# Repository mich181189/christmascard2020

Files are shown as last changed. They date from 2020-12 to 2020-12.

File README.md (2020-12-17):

# christmascard2020
I made a christmas card with WS2812B LEDs and it supports Micropython!

There is some HTML documentation generated from the /docs/ folder at https://mich181189.github.io/christmascard2020/index.html

The board is intended to run Micropython, a fork of which (with some additions to support this hardware) is available here: https://github.com/mich181189/christmascard2020_micropython

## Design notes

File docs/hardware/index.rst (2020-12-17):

Christmas Card Hardware / Design Notes
======================================

.. toctree::
   :maxdepth: 2

   advanced
   ../flash_sh

.. rubric:: The hardware consists of:

* STM32F401RET6 Microcontroller
* 28 WS2812B LEDs (`Datasheet <../_static/WS2812B.pdf>`_)
* LM75B i2c Temperature Sensor
* A USB Connector

The microcontroller was chosen as the cheapest one available on `JLCPCB's SMT assembly service <https://jlcpcb.com/smt-assembly>`_ with decent Micropython support. This entire project was desgned in a bit of a rush 😅 

The USB connector is a full-sized B connector. This is because it was relatively easy to solder on once I received the PCBs from JLC - I didn't fancy separately reflowing a connector on - if I had more time, I'd have chosen micro-B or maybe even USB-C

The name label was done with a Brother P-Touch label maker. I had originally intended to Sharpie on names, but it started to smudge a bit. I realised I had some 6mm tape for my label maker that worked nicely.

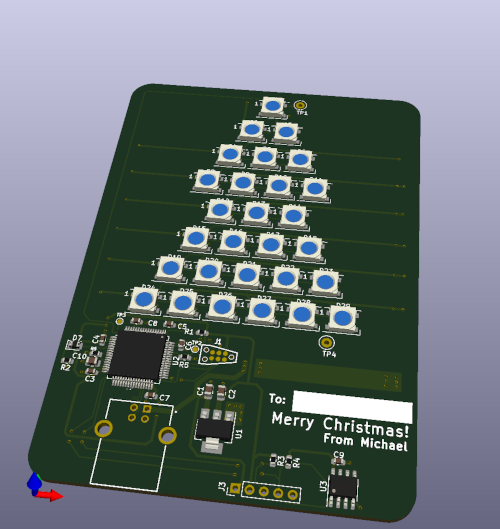
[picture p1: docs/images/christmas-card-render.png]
Render of PCB


.. rubric:: Some Links

* The Schematic `is available as a PDF <../_static/schematic_1_0.pdf>`_ 
* The hardware design is `available on GitHub <https://github.com/mich181189/christmascard2020>`_
    * If you want to play with  the hardware design, it was designed in `KiCad <https://kicad.org/>`_
* The board runs `Micropython <http://micropython.org/>`_
* In case you need the firmware for some reason:
    * `firmware0.bin <../_static/firmware0.bin>`_ (0x08000000)
    * `firmware1.bin <../_static/firmware1.bin>`_ (0x08020000)
    * `init_fs.bin <../_static/init_fs.bin>`_ (0x8004000)
    * :doc:`../flash_sh`

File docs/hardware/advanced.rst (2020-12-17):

More Advanced Ideas
====================
This page contains some hints/tips/suggestions for things you might want to try if you get bored of the board as is.

Connecting More LEDs
---------------------
There are two test points on the board, TP1 and TP4 that are in the LED chain. *TP1* is the output of *PB0* on the microcontroller. This is probbaly of limited use for extension since while you could tap into it, the LEDs would be in parallel with those on the board, which doesn't sound incredibly useful. *TP4* however, may be more useful. It is the *DOUT* pin of the last LED in the chain. This could be connected to a string of WS2812 LEDs. Then, when you init the module, you could specify the extra count

>>> ws2812.init(28+60)

I really have no idea how many LEDs could be added this way, however the code for driving them uses quite a memory-efficient way of sending the data, so I suspect the number is actually quite high. Memory usage is 3 bytes per LED, plus 48 bytes of scratch space for the actual sending functions.

Connecting I2C Peripherals
--------------------------
There is a pin header on the bottom edge of the board. As well as power and data, this connects to the I2C bus (shared with the LM75 temperature sensor)

+-----------------+
| Pin  | Function |
+======+==========+
| 1    | +5V      |
+------+----------+
| 2    | +3.3V    |
+------+----------+
| 3    | SCL      |
+------+----------+
| 4    | SDA      |
+------+----------+
| 5    | GND      |
+------+----------+

.. warning::
	The SCL and SDA data lines run at 3.3V. 5V devices can be connected, as long as they do not try to pull these lines to the +5V rail - Since I2C devices should only be pulling the line low, this should not be a problem, except that some (many?) breakout boards contain their own pullup resistors to their power rail.

These devices can then be addressed much like any other device. For example, if you were trying to communicate with the LM75B sensor on the board using raw I2C commands:

>>> import machine
>>> i2c = machine.I2C(1, freq=400000) # 400KHz I2C bus on channel 1 (the one broken out on the connector)
>>> result = i2c.readfrom_mem(72, 0x00, 2) # read 2 bytes from register 0 on device with address 72 aka 0x48
>>> result
b'\x17\xa0'

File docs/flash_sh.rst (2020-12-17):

My Board Flashing Script
==========================

This is the script I used to flash the board. It was run from ports/stm32 in the Micropython source tree `(GitHub Link) <https://github.com/mich181189/christmascard2020_micropython>`_

It makes use of an initial filesystem I created by copying the files to a board, then dumping the relevant section of flash. I then used the *fatlabel* utility to relabel it as CCARD2020

I used an STLink V2 for the flashing.

.. literalinclude:: examples/flash.sh

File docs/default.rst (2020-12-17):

The Default main.py Script
==========================

This is the `main.py` file that was on the board when you received it, in case you need it

.. literalinclude:: examples/default_main.py

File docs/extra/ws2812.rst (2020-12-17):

WS2812 Module
==============
.. py:module::ws2812

.. py:function:: init(count)
	Sets up the WS2812 module to handle *count* LEDs

.. py:function:: set_led(led, red, green, blue)

	Sets the colour of the led, identified by index *led* to the colour specified by *red*, *green* and *blue* which are integers from 0 to 255.

	.. note::
 		These LEDs are very bright! Values between 0 and 25 are probably easily bright enough! Setting too many LEDs to a high value can cause fairly high current draw, and the PCB can get very hot.

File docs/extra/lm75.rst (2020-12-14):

lm75 Module
===========
.. py:module::lm75

Handler for LM75 i2c temperature sensor. The LM75 temperature sensor is connected to the I2C bus, and continuously measures temperature, unless it is explicitly shutdown (see :py:meth:`lm75.LM75.shutdown`)

.. py:module:: lm75
.. py:class:: LM75(i2c [, address=72])

	Constructs an LM75 object. Takes an I2C object and optionally, an address of the LM75

	.. py:method:: get_temperature()

	Gets the current temperature, as measured by the LM75 module, in `degrees celsius <https://en.wikipedia.org/wiki/Celsius>`_

	Reading while the device is shutdown will result in the last temperature reading captured before the sensor was shutdown.

	.. py:method:: shutdown()

	Shuts down the LM75 temperature sensor, reducing current consumption. Also might be useful to prevent the temperature sensor from heating itself up too much, affecting measurements.

	To reverse this, call :py:meth:`wakeup`

	.. py:method:: wakeup()

	Wakes up the LM75, after a call to :py:meth:`shutdown`

	.. py:method:: is_shutdown()

	Returns True if the LM75 sensor is in a shutdown state

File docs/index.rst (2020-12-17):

.. Christmas Card 2020 documentation master file, created by
   sphinx-quickstart on Mon Dec 14 18:30:20 2020.
   You can adapt this file completely to your liking, but it should at least
   contain the root `toctree` directive.

Welcome to the Christmas Card 2020 docs!
===============================================

If you are reading this, you have probably received a christmas card from me. Or, maybe, you stumbled upon this project and are curious about  what I created.
This card is, in fact, a `Micropython <http://micropython.org/>`_ development board! It can, of course, be 
used as a simple decoration, but it is also programmable to your liking!

Table Of Contents
======================

.. toctree::
   :maxdepth: 2

   getting_started
   Hardware / Design Notes <hardware/index>
   extra/index
   default

Indices and tables
==================

* :ref:`genindex`
* :ref:`modindex`
* :ref:`search`

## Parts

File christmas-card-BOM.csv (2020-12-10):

Comment | Designator | Footprint | LCSC
4.7uF | C1,C2,C10 | Capacitor_SMD:C_0805_2012Metric | C1779
100nF | C3,C4,C5,C6,C7,C8,C9 | Capacitor_SMD:C_0603_1608Metric | C14663
WS2812B | D1,D2,D3,D4,D5,D6,D8,D9,D10,D11,D12,D13,D14,D15,D16,D17,D18,D19,D20,D21,D22,D23,D24,D25,D26,D27,D28,D29 | LED_SMD:LED_WS2812B_PLCC4_5.0x5.0mm_P3.2mm | C114586
LED_ALT | D7 | Diode_SMD:D_0805_2012Metric | C84256
10K | R1,R3,R4,R5,R6 | Resistor_SMD:R_0603_1608Metric | C25804
270R | R2 | Resistor_SMD:R_0603_1608Metric | C22966
AMS1117-3.3 | U1 | Package_TO_SOT_SMD:SOT-223-3_TabPin2 | C6186
STM32F401RETx | U2 | Package_QFP:LQFP-64_10x10mm_P0.5mm | C116978
LM75B | U3 | Package_SO:SOIC-8_3.9x4.9mm_P1.27mm | C34565

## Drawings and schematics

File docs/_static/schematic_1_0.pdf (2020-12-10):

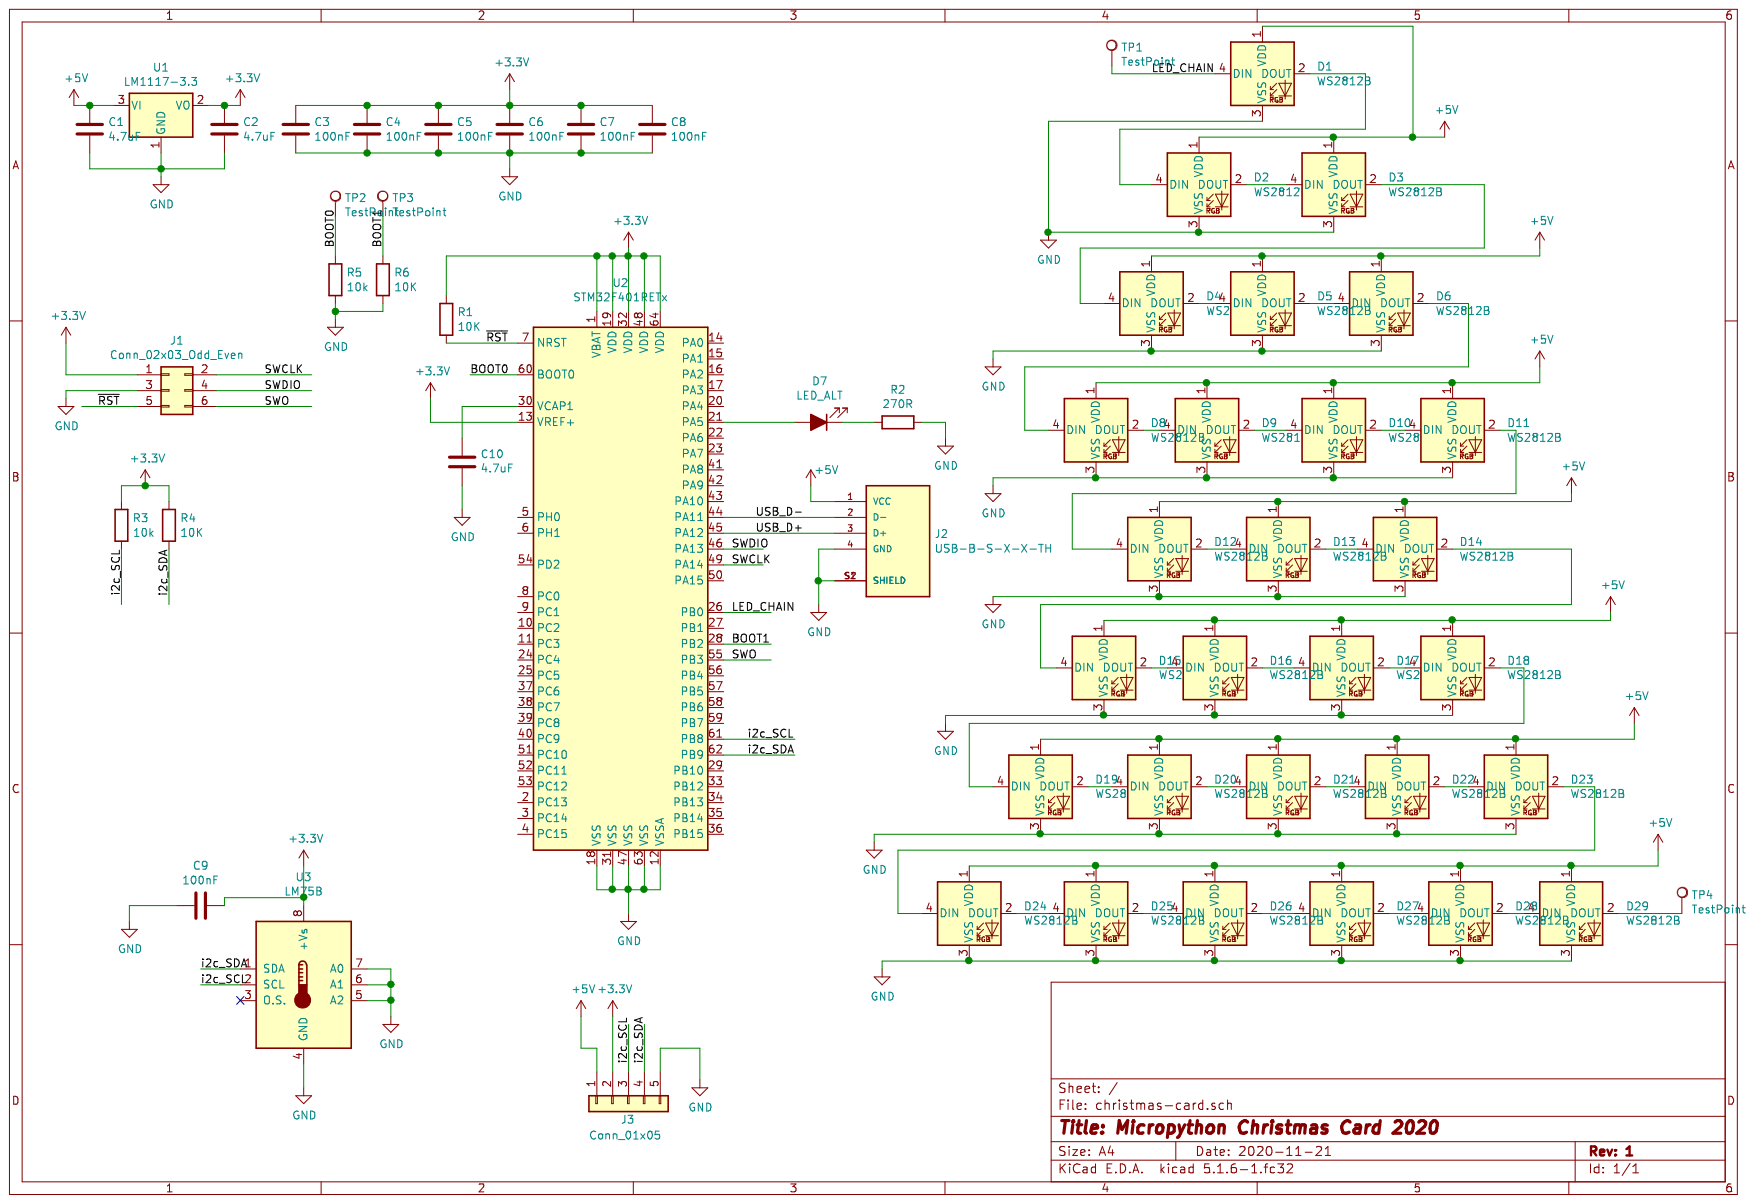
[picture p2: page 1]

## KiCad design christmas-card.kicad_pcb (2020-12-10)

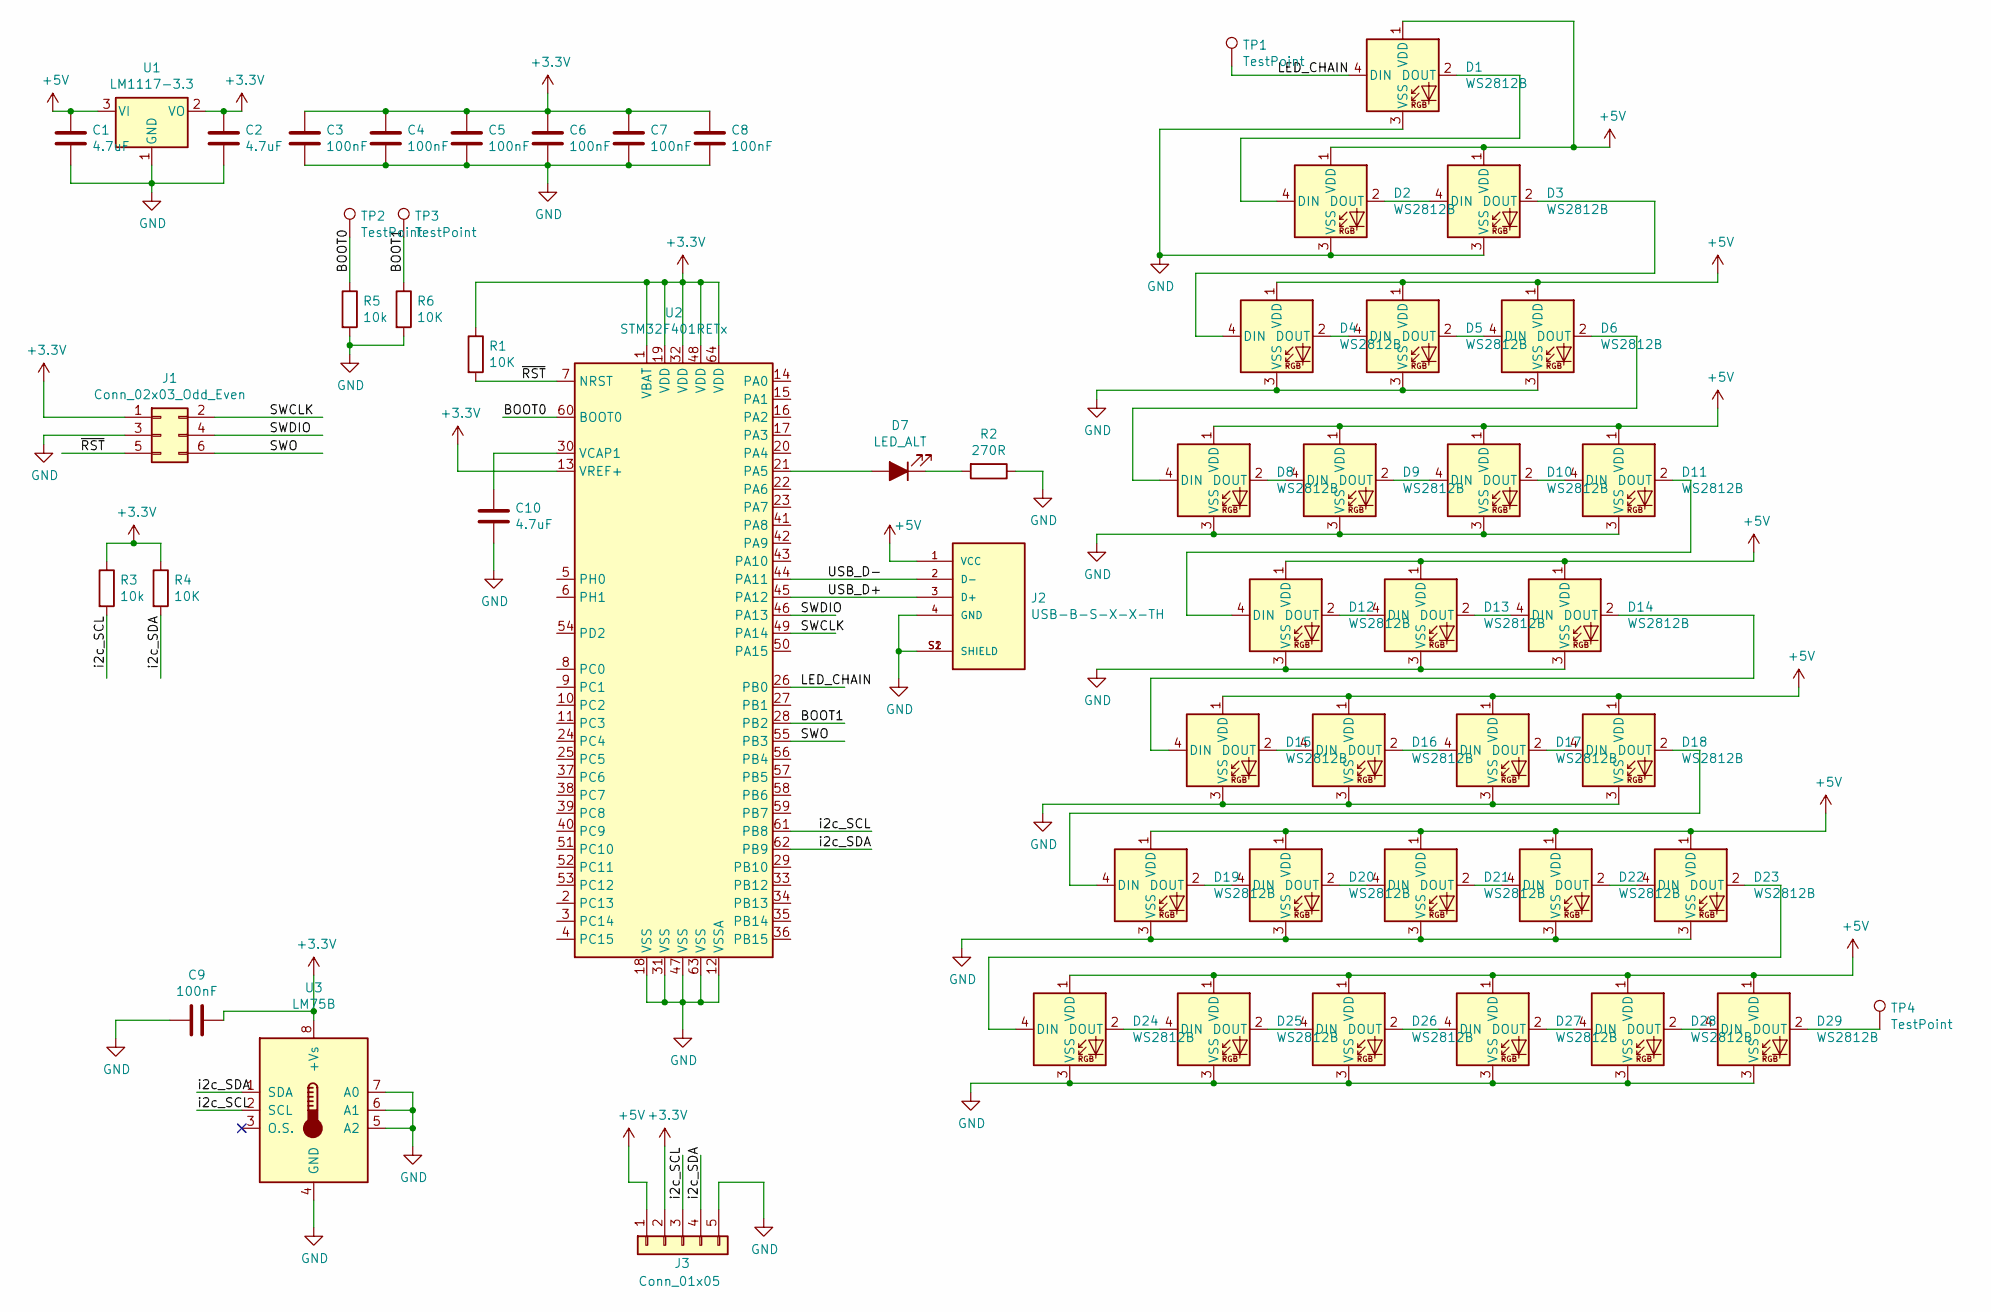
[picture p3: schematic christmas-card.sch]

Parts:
C1, C2, C10: 4.7uF; C_0805_2012Metric
C3, C4, C5, C6, C7, C8, C9: 100nF; C_0603_1608Metric
D1, D2, D3, D4, D5, D6, D8, D9, D10, D11, D12, D13, D14, D15, D16, D17, D18, D19, D20, D21, D22, D23, D24, D25, D26, D27, D28, D29: WS2812B; LED_WS2812B_PLCC4_5.0x5.0mm_P3.2mm
D7: LED_ALT; D_0805_2012Metric
J1: Conn_02x03_Odd_Even; TC2030-MCP-NL
J2: USB-B-S-X-X-TH; SAMTEC_USB-B-S-X-X-TH; PARTREV Q
J3: Conn_01x05; PinHeader_1x05_P2.54mm_Vertical
R1, R4, R6: 10K; R_0603_1608Metric
R2: 270R; R_0603_1608Metric
R3, R5: 10k; R_0603_1608Metric
TP1, TP4: TestPoint; TestPoint_Loop_D1.80mm_Drill1.0mm_Beaded
TP2, TP3: TestPoint; TestPoint_Pad_D1.0mm
U1: LM1117-3.3; SOT-223-3_TabPin2
U2: STM32F401RETx; LQFP-64_10x10mm_P0.5mm
U3: LM75B; SOIC-8_3.9x4.9mm_P1.27mm

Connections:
+3V3: C2.1, C3.1, C4.1, C5.1, C6.1, C7.1, C8.1, C9.1, J1.1, J3.2, R1.1, R3.1, R4.1, U1.2 (VO), U2.1 (VBAT), U2.13 (VREF+), U2.19 (VDD), U2.32 (VDD), U2.48 (VDD), U2.64 (VDD), U3.8 (+Vs)
+5V: C1.1, D1.1 (VDD), D2.1 (VDD), D3.1 (VDD), D4.1 (VDD), D5.1 (VDD), D6.1 (VDD), D8.1 (VDD), D9.1 (VDD), D10.1 (VDD), D11.1 (VDD), D12.1 (VDD), D13.1 (VDD), D14.1 (VDD), D15.1 (VDD), D16.1 (VDD), D17.1 (VDD), D18.1 (VDD), D19.1 (VDD), D20.1 (VDD), D21.1 (VDD), D22.1 (VDD), D23.1 (VDD), D24.1 (VDD), D25.1 (VDD), D26.1 (VDD), D27.1 (VDD), D28.1 (VDD), D29.1 (VDD), J2.1 (VCC), J3.1, U1.3 (VI)
/BOOT0: R5.1, TP2.1, U2.60 (BOOT0)
/BOOT1: R6.1, TP3.1, U2.28 (PB2)
/LED_CHAIN: D1.4 (DIN), TP1.1, U2.26 (PB0)
/SWCLK: J1.2, U2.49 (PA14)
/SWDIO: J1.4, U2.46 (PA13)
/SWO: J1.6, U2.55 (PB3)
/USB_D+: J2.3 (D+), U2.45 (PA12)
/USB_D-: J2.2 (D-), U2.44 (PA11)
/i2c_SCL: J3.3, R3.2, U2.61 (PB8), U3.2 (SCL)
/i2c_SDA: J3.4, R4.2, U2.62 (PB9), U3.1 (SDA)
/~RST: J1.5, R1.2, U2.7 (NRST)
GND: C1.2, C2.2, C3.2, C4.2, C5.2, C6.2, C7.2, C8.2, C9.2, C10.1, D1.3 (VSS), D2.3 (VSS), D3.3 (VSS), D4.3 (VSS), D5.3 (VSS), D6.3 (VSS), D8.3 (VSS), D9.3 (VSS), D10.3 (VSS), D11.3 (VSS), D12.3 (VSS), D13.3 (VSS), D14.3 (VSS), D15.3 (VSS), D16.3 (VSS), D17.3 (VSS), D18.3 (VSS), D19.3 (VSS), D20.3 (VSS), D21.3 (VSS), D22.3 (VSS), D23.3 (VSS), D24.3 (VSS), D25.3 (VSS), D26.3 (VSS), D27.3 (VSS), D28.3 (VSS), D29.3 (VSS), J1.3, J2.4 (GND), J2.S1 (SHIELD), J2.S2 (SHIELD), J3.5, R2.1, R5.2, R6.2, U1.1 (GND), U2.12 (VSSA), U2.18 (VSS), U2.31 (VSS), U2.47 (VSS), U2.63 (VSS), U3.4 (GND), U3.5 (A2), U3.6 (A1), U3.7 (A0)
unnamed: C10.2, U2.30 (VCAP1)
unnamed: D1.2 (DOUT), D2.4 (DIN)
unnamed: D2.2 (DOUT), D3.4 (DIN)
unnamed: D3.2 (DOUT), D4.4 (DIN)
unnamed: D4.2 (DOUT), D5.4 (DIN)
unnamed: D5.2 (DOUT), D6.4 (DIN)
unnamed: D6.2 (DOUT), D8.4 (DIN)
unnamed: D7.1 (K), R2.2
unnamed: D7.2 (A), U2.21 (PA5)
unnamed: D8.2 (DOUT), D9.4 (DIN)
unnamed: D10.2 (DOUT), D11.4 (DIN)
unnamed: D9.2 (DOUT), D10.4 (DIN)
unnamed: D11.2 (DOUT), D12.4 (DIN)
unnamed: D12.2 (DOUT), D13.4 (DIN)
unnamed: D13.2 (DOUT), D14.4 (DIN)
unnamed: D14.2 (DOUT), D15.4 (DIN)
unnamed: D15.2 (DOUT), D16.4 (DIN)
unnamed: D16.2 (DOUT), D17.4 (DIN)
unnamed: D17.2 (DOUT), D18.4 (DIN)
unnamed: D18.2 (DOUT), D19.4 (DIN)
unnamed: D19.2 (DOUT), D20.4 (DIN)
unnamed: D20.2 (DOUT), D21.4 (DIN)
unnamed: D21.2 (DOUT), D22.4 (DIN)
unnamed: D22.2 (DOUT), D23.4 (DIN)
unnamed: D23.2 (DOUT), D24.4 (DIN)
unnamed: D24.2 (DOUT), D25.4 (DIN)
unnamed: D25.2 (DOUT), D26.4 (DIN)
unnamed: D26.2 (DOUT), D27.4 (DIN)
unnamed: D27.2 (DOUT), D28.4 (DIN)
unnamed: D28.2 (DOUT), D29.4 (DIN)
unnamed: D29.2 (DOUT), TP4.1

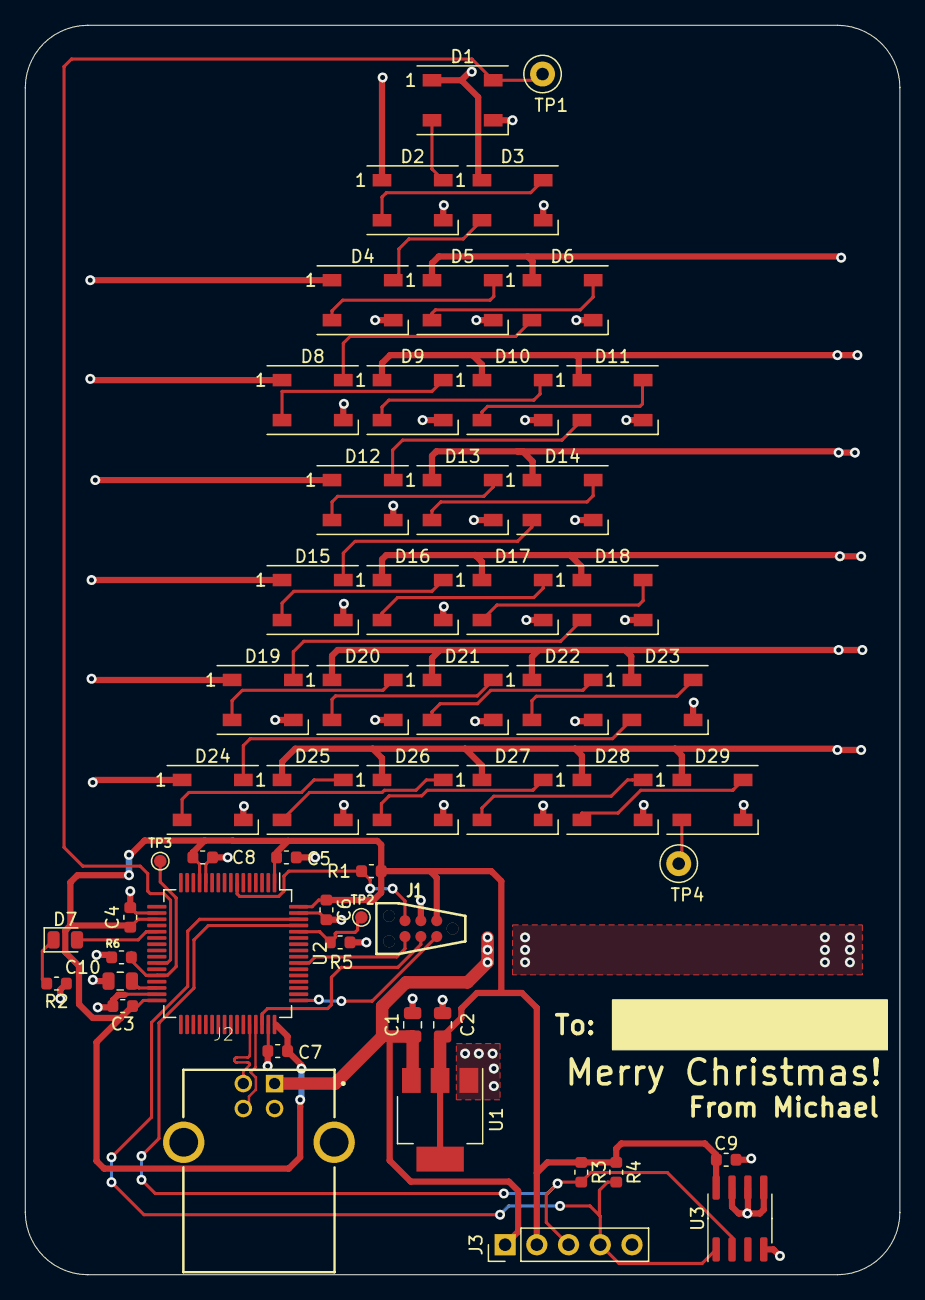
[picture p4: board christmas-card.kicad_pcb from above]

Board: 2 copper layers, 70.0 x 100.0 mm, 55 parts (0 on the bottom side), 45 nets.

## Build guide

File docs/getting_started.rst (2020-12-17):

Getting Started
===============

.. contents::
    :depth: 3

An introduction to the Hardware
-------------------------------

The christmas card is a `Micropython <http://micropython.org/>`_ board, with 28 WS2812 LEDs (sometimes called NeoPixels). It has a USB connector, providing it with 5V power. As supplied, it pulls about 20mA so it can run from a decent power bank for quite a while. This depends very much on the script that's running though.

It can be simply used as a christmas decoration, though it can also be a lot more fun than that!

When plugged into a computer, it appears as both a mass storage device, and a serial port. Together, these allow the pattern to be customised.

There is also a temperature sensor on the board. Because why not?!

For more details of the hardware specs, see :doc:`hardware/index`

Connecting to the Board
-----------------------

Plug one end of a USB cable into the board. Plug the other end into your computer. Yep, thats all there is to it. Now read the next sections for details of what you can do with this!

Storage
^^^^^^^^

When connected to a computer, it will show up as a storage device. On this storage device you will find a few files:

* **boot.py** - this is run at startup, to configure the hardware. It doesn't contain much, and you can probably ignore it.
* **main.py** - This contains the script that is run when the board is powered up. It is run after boot.py - this is where the patterns are! As supplied, it contains :doc:`default`
* **pybcdc.inf** This file helps Windows to figure out what to do with the board. You can ignore this.

.. note::
    This is a very small filesystem, containing only about 64Kb of storage. It should only be used to hold Python scripts you want to run on the board. Try not to write to it more often than you need to since the flash memory on the microcontroller may eventually wear out.

Serial
^^^^^^^

The board shows up as a USB serial device. this runs at a baud rate of **115200**

When you first connect to it, you won't see much since it's running the pattern. You can press **Ctrl+C** to interrupt the running script, and get a Micropython prompt. If you want to restart the board from this prompt, you can use press **Ctrl+D**

The LEDs
--------

There are 28 WS2812 LEDs on the board. They are digitally controllable, with each taking three values in the range 0-255 - one for each of red, green and blue.

.. note::
    Values above about 30 are *very* bright, and if enough LEDs are lit at high levels, the board can get very hot quite quickly!

There is a single data connector to each LED, and they are daisy chained together. In effect, they form a shift register. The actual wire protocol has quite exacting timing, since the same line is used for both data and clock. This complexity is taken care of for you by the firmware on the board!

In order to communicate with the LEDs, we firstly need to tell the firmware how many are connected. Since there are 28 on the board, this is the number we will use:

>>> import ws2812
>>> ws2812.init(28)

Now we can set the colours of the LEDs:

>>> ws2812.set_led(4, 15, 20,25) # Set LED 4 to R,G,B values 15,20,25

Taking the Temperature
----------------------

As previously mentioned, there is a temperature sensor on the board. Reading the temperature using it is quite easy:

>>> from lm75 import LM75
>>> from machine import I2C
>>> i2c = I2C(1) # 1 is the hardware ID for the I2C channel the sensor is attached to
>>> lm75 = LM75(i2c)
>>> lm75.get_temperature()
24.75

Firstly, we import the :py:mod:`lm75` module. This is built into the firmware of the board. (If you're really curious, the source for it can be `found on GitHub <https://github.com/mich181189/christmascard2020_micropython/blob/master/drivers/lm75/lm75.py>`_ )
We then import the I2C module (docs for which can be found on the `Micropython I2C docs page <http://docs.micropython.org/en/latest/library/machine.I2C.html>`_) and set up I2C channel 1 (which is the only one broken out on this board) with a speed of 400kHz.
We then create an LM75 object, using the i2c object we just created. Then we can query the temperature.

One thing to keep in mind is that the LM75 sensor is constantly reading the temperature. This actually means it can heat itself up! To avoid this, you can put it into a shutdown mode when you're not using it, then wake it up when you want to start measuring again. Once you have woken it up, you probably want to give it a few hundred milliseconds to read the temperature again, otherwise you will get the old value from before it was shutdown until it re-measures.

>>> lm75.shutdown()
>>> lm75.is_shutdown()
True
>>> lm75.wakeup()
>>> lm75.is_shutdown()
False
>>> # you can now make your measurement after a short delay
>>> lm75.get_temperature()
25.25

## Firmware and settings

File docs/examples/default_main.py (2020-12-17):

import ws2812
import utime
from lm75 import LM75
from machine import I2C
import random

i2c = I2C(1, freq=400000)
lm75 = LM75(i2c)

# take a reading, then shutdown the LM75 so it doesn't heat itself up
lm75.wakeup()
utime.sleep_ms(300)
start_temperature = lm75.get_temperature()
lm75.shutdown()

# Start the WS2812 handling stuff
ws2812.init(28)

def pattern_twinkle(starting):
	# The base LED patterns
	leds = starting

	# create the state object
	class State:
		twinkle_state = 0
		twinkle_led = 0
	state = State()

	# set the LEDs to their starting pattern
	for i in range(0,len(leds)):
		(r,g,b) = leds[i]
		ws2812.set_led(i, r,g,b)

	def twinkle_next(state):
		if state.twinkle_state == 0:
			(r,g,b) = leds[state.twinkle_led]
			ws2812.set_led(state.twinkle_led, r,g,b)
			state.twinkle_led = random.randint(0, len(leds)-1)
			(r,g,b) = leds[state.twinkle_led]
			if r > 0:
				r = r + 10
			if g > 0:
				g = g + 10
			if b > 0:
				b = b + 10
			ws2812.set_led(state.twinkle_led, r,g,b)
			state.twinkle_state = state.twinkle_state + 1
		elif state.twinkle_state == 1:
			(r,g,b) = leds[state.twinkle_led]
			if r > 0:
				r = r + 15
			if g > 0:
				g = g + 15
			if b > 0:
				b = b + 15
			ws2812.set_led(state.twinkle_led, r,g,b)
			state.twinkle_state = state.twinkle_state + 1
		elif state.twinkle_state == 2:
			(r,g,b) = leds[state.twinkle_led]
			if r > 0:
				r = r + 10
			if g > 0:
				g = g + 10
			if b > 0:
				b = b + 10
			ws2812.set_led(state.twinkle_led, r,g,b)
			state.twinkle_state = 0
		
		
	while True:
		utime.sleep_ms(100)
		twinkle_next(state)

def pattern_fade(starting_leds):
	class LEDState:
		STATE_WAIT = 0
		STATE_RAMP_UP = 1
		STATE_RAMP_DOWN = 2

		def __init__(self, i, r, g, b):
			self.i = i
			self.wait_count = random.randint(0, 35)
			self.base_r = r
			self.base_g = g
			self.base_b = b
			self.current_state = 0
			self.step = 0

		def run(self):
			if self.current_state == self.STATE_RAMP_UP:
				self.step += 1
				if self.step >= 7:
					self.current_state = self.STATE_RAMP_DOWN
			elif self.current_state == self.STATE_RAMP_DOWN:
				self.step -= 1
				if self.step <= 0:
					self.current_state = self.STATE_WAIT
					self.wait_count = 0
			else:
				# the aim of thisis to make something that looks sort of chaotic
				if self.wait_count < (75 - 2*(self.i % 3) + (self.i % 2) - (self.i % 4)) - self.i:
					self.wait_count += 1
					#ws2812.set_led(self.i, 0,0,0)
				else:
					self.current_state = self.STATE_RAMP_UP
			r = 0
			g = 0
			b = 0
			if self.base_r > 0:
				r = self.base_r	 + self.step*2 - 5
			if self.base_g > 0:
				g = self.base_g + self.step*2 - 5
			if self.base_b > 0:
				b = self.base_b + self.step*2 - 5
			ws2812.set_led(self.i, int(r), int(g), int(b))

	leds = []
	i = 0
	for l in starting_leds:
		r,g,b = l
		leds.append(LEDState(i, r, g, b))
		i += 1

	while True:
		for l in leds:
			l.run()
		utime.sleep_ms(50)


def pattern1():
	leds = [
		(10,10,0),
		(0,10,0),(0,10,0),
		(0,10,0),(0,10,0),(0,10,0),
		(10,0,0),(0,10,0),(0,10,0),(10,0,0),
		(0,10,0),(0,10,0),(0,10,0),
		(10,0,0),(0,10,0),(0,10,0),(10,0,0),
		(0,10,0),(0,10,0),(0,10,0),(0,10,0),(0,10,0),
		(10,0,0),(0,10,0),(0,10,0),(0,10,0),(0,10,0),(10,0,0),
		]
	if int(start_temperature * 100) % 2 == 0:
		pattern_twinkle(leds)
	else:
		pattern_fade(leds)

def pattern2():
	leds = [
		(10,10,0),
		(0,0,10),(0,0,10),
		(0,0,10),(0,0,10),(0,0,10),
		(10,0,10),(0,0,10),(0,0,10),(10,0,10),
		(0,0,10),(0,0,10),(0,0,10),
		(10,0,10),(0,0,10),(0,0,10),(10,0,10),
		(0,0,10),(0,0,10),(0,0,10),(0,0,10),(0,0,10),
		(10,0,10),(0,0,10),(0,0,10),(0,0,10),(0,0,10),(10,0,10),
		]
	if int(start_temperature * 100) % 2 == 0:
		pattern_twinkle(leds)
	else:
		pattern_fade(leds)

def pattern3():
	leds = [
		(10,10,0),
		(10,0,0),(10,0,0),
		(10,0,0),(10,0,0),(10,0,0),
		(0,10,5),(10,0,0),(10,0,0),(0,10,5),
		(10,0,0),(10,0,0),(10,0,0),
		(0,10,5),(10,0,0),(10,0,0),(0,10,5),
		(10,0,0),(10,0,0),(10,0,0),(10,0,0),(10,0,0),
		(0,10,5),(10,0,0),(10,0,0),(10,0,0),(10,0,0),(0,10,5),
		]
	if int(start_temperature * 100) % 2 == 0:
		pattern_twinkle(leds)
	else:
		pattern_fade(leds)

def pattern4():
	while True:
		for i in range(28):
			ws2812.set_led(i, random.randint(0,15),random.randint(0,15),random.randint(0,15))
		utime.sleep_ms(300)

random.seed()

print("Starting temperature is %f" % (start_temperature,))

if start_temperature < 20:
	pattern2()
elif start_temperature < 25:
	pattern1()
elif start_temperature < 26:
	pattern4()
else:
	pattern3()
